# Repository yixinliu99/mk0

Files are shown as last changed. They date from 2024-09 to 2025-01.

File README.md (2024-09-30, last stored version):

# mk0
Modularized Keyboard 0

The goal of this project is to build a full-fledged and modularized keyboard from scratch, including PCBs and a case.

# Prelude
The last time I designed a PCB was for the final project of my Bachelor degree, which was almost 4 years ago. Some refreshing on how to design PCB is definetely needed for me. I have found https://wiki.ai03.com/books/pcb-design/chapter/pcb-designer-guide pretty useful as it covers not only general PCB designing but also how keyboards work.

# Roadmap
- PCB design (keyboard + STM32F303)
- Firmware. Probably will use some code from QMK (https://github.com/qmk/qmk_firmware)
- Case design
- Fabrication

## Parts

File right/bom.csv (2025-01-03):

Id | Designator | Footprint | Quantity | Designation | Supplier and ref
1 | C11,C3,C4,C12,C8,C10,C2 | C_0805_2012Metric_Pad1.18x1.45mm_HandSolder | 7 | 100nF
5 | SW2 | SW_SPST_CK_RS282G05A3 | 1 | SW_BOOT
7 | D20,D33,D3,D6,D27,D21,D28,D5,D23,D10,D18,D1,D25,D2,D19,D4,D30,D24,D11,D16,D31,D29,D13,D26,D7,D9,D12,D17,D32,D8,D22,D14,D15 | D_SOD-323_HandSoldering | 33 | D
11 | U1 | SOT-23 | 1 | LM3480-3.3
13 | R3 | R_0805_2012Metric_Pad1.20x1.40mm_HandSolder | 1 | 10K
15 | C1,C9,C7 | C_0805_2012Metric_Pad1.18x1.45mm_HandSolder | 3 | 4.7uF
16 | C14,C13 | C_0805_2012Metric_Pad1.18x1.45mm_HandSolder | 2 | 20pF
17 | J2 | Plug_3.5mm_CUI_SP-3541 | 1 | AudioJack4
18 | C5 | C_0805_2012Metric_Pad1.18x1.45mm_HandSolder | 1 | 1uF
21 | J1 | USB_C_Receptacle_HRO_TYPE-C-31-M-12 | 1 | USB_C_Receptacle_USB2.0_16P
22 | R2,R1 | R_0805_2012Metric_Pad1.20x1.40mm_HandSolder | 2 | 5.1K
33 | U2 | LQFP-48_7x7mm_P0.5mm | 1 | STM32F072CBTx
34 | SW1 | SW_SPST_CK_RS282G05A3 | 1 | SW_RESET
36 | Y1 | Crystal_SMD_2012-2Pin_2.0x1.2mm_HandSoldering | 1 | 8MHz
41 | C6 | C_0805_2012Metric_Pad1.18x1.45mm_HandSolder | 1 | 10nF
45 | R4 | R_0805_2012Metric_Pad1.20x1.40mm_HandSolder | 1 | 390
49 | J3 | Harwin_M20-89010xx_1x10_P2.54mm_Horizontal | 1 | Conn_ARM_JTAG_SWD_10

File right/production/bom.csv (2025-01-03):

Designator | Footprint | Quantity | Value | LCSC Part #
C1, C7, C9 | 0805 | 3 | 4.7uF
C10, C11, C12, C2, C3, C4, C8 | 0805 | 7 | 100nF
C13, C14 | 0805 | 2 | 20pF
C5 | 0805 | 1 | 1uF
C6 | 0805 | 1 | 10nF
D1, D10, D11, D12, D13, D14, D15, D16, D17, D18, D19, D2, D20, D21, D22, D23, D24, D25, D26, D27, D28, D29, D3, D30, D31, D32, D33, D4, D5, D6, D7, D8, D9 | D_SOD-323_HandSoldering | 33 | D
J1 | USB_C_Receptacle_HRO_TYPE-C-31-M-12 | 1 | USB_C_Receptacle_USB2.0_16P
J2 | Plug_3.5mm_CUI_SP-3541 | 1 | AudioJack4
J3 | Harwin_M20-89010xx_1x10_P2.54mm_Horizontal | 1 | Conn_ARM_JTAG_SWD_10
R1, R2 | 0805 | 2 | 5.1K
R3 | 0805 | 1 | 10K
R4 | 0805 | 1 | 390
SW1 | SW_SPST_CK_RS282G05A3 | 1 | SW_RESET
SW10 | SW_Cherry_MX_1.00u_Plate | 1 | tab
SW11 | SW_Cherry_MX_1.00u_Plate | 1 | q
SW12 | SW_Cherry_MX_1.00u_Plate | 1 | w
SW13 | SW_Cherry_MX_1.00u_Plate | 1 | e
SW14 | SW_Cherry_MX_1.00u_Plate | 1 | r
SW15 | SW_Cherry_MX_1.00u_Plate | 1 | t
SW16 | SW_Cherry_MX_1.00u_Plate | 1 | [
SW17 | SW_Cherry_MX_1.00u_Plate | 1 | caps
SW18 | SW_Cherry_MX_1.00u_Plate | 1 | a
SW19 | SW_Cherry_MX_1.00u_Plate | 1 | s
SW2 | SW_SPST_CK_RS282G05A3 | 1 | SW_BOOT
SW20 | SW_Cherry_MX_1.00u_Plate | 1 | d
SW21 | SW_Cherry_MX_1.00u_Plate | 1 | f
SW22 | SW_Cherry_MX_1.00u_Plate | 1 | g
SW23 | SW_Cherry_MX_1.00u_Plate | 1 | ->
SW24 | SW_Cherry_MX_2.00u_Plate | 1 | z
SW25 | SW_Cherry_MX_1.00u_Plate | 1 | z
SW26 | SW_Cherry_MX_1.00u_Plate | 1 | x
SW27 | SW_Cherry_MX_1.00u_Plate | 1 | c
SW28 | SW_Cherry_MX_1.00u_Plate | 1 | v
SW29 | SW_Cherry_MX_1.00u_Plate | 1 | b
SW3 | SW_Cherry_MX_1.00u_Plate | 1 | `
SW30 | SW_Cherry_MX_1.00u_Plate | 1 | custom2
SW31 | SW_Cherry_MX_1.00u_Plate | 1 | ctrl
SW32 | SW_Cherry_MX_1.00u_Plate | 1 | menu
SW33 | SW_Cherry_MX_1.00u_Plate | 1 | alt
SW34, SW35 | SW_Cherry_MX_1.00u_Plate | 2 | space
SW4 | SW_Cherry_MX_1.00u_Plate | 1 | 1
SW5 | SW_Cherry_MX_1.00u_Plate | 1 | 2
SW6 | SW_Cherry_MX_1.00u_Plate | 1 | 3
SW7 | SW_Cherry_MX_1.00u_Plate | 1 | 4
SW8 | SW_Cherry_MX_1.00u_Plate | 1 | 5
SW9 | SW_Cherry_MX_1.00u_Plate | 1 | -
U1 | SOT-23 | 1 | LM3480-3.3
U2 | LQFP-48_7x7mm_P0.5mm | 1 | STM32F072CBTx
Y1 | Crystal_SMD_2012-2Pin_2.0x1.2mm_HandSoldering | 1 | 8MHz

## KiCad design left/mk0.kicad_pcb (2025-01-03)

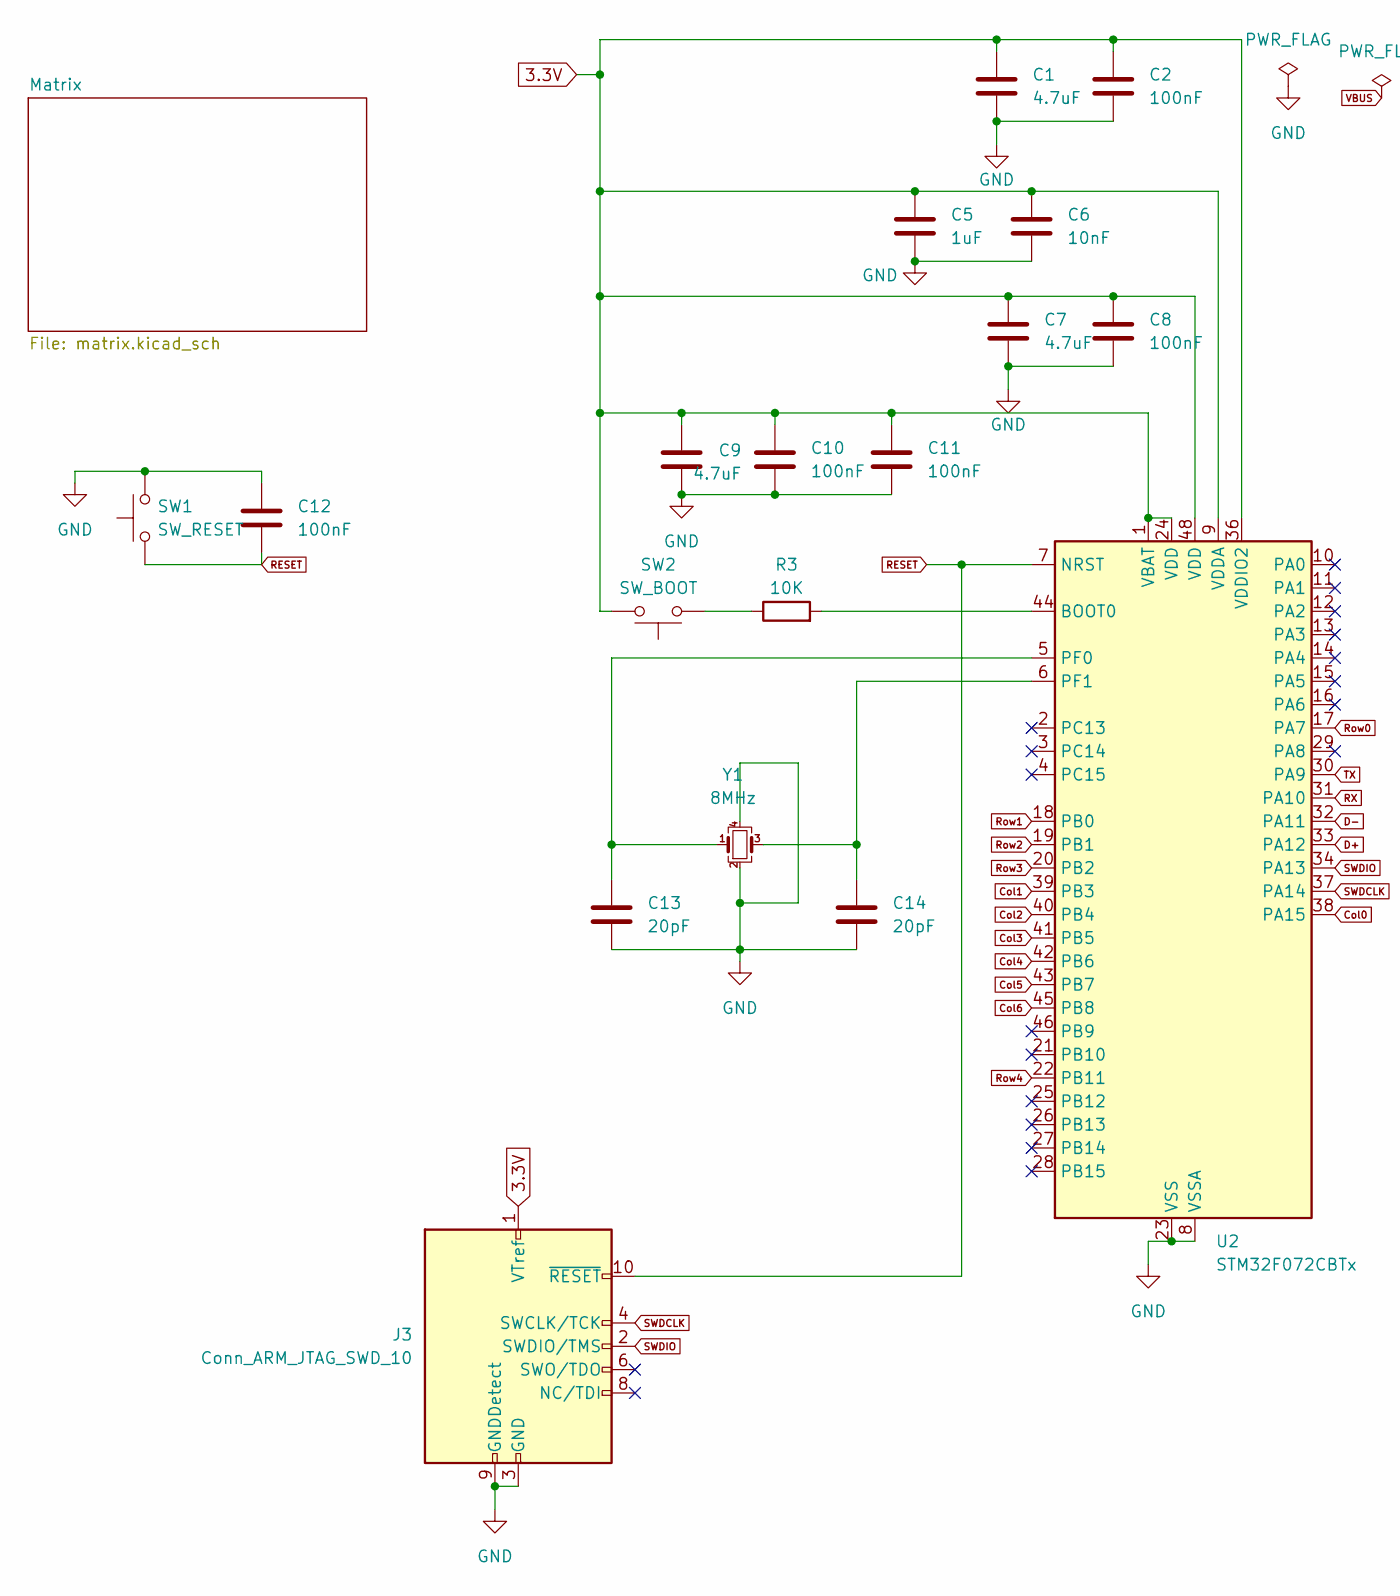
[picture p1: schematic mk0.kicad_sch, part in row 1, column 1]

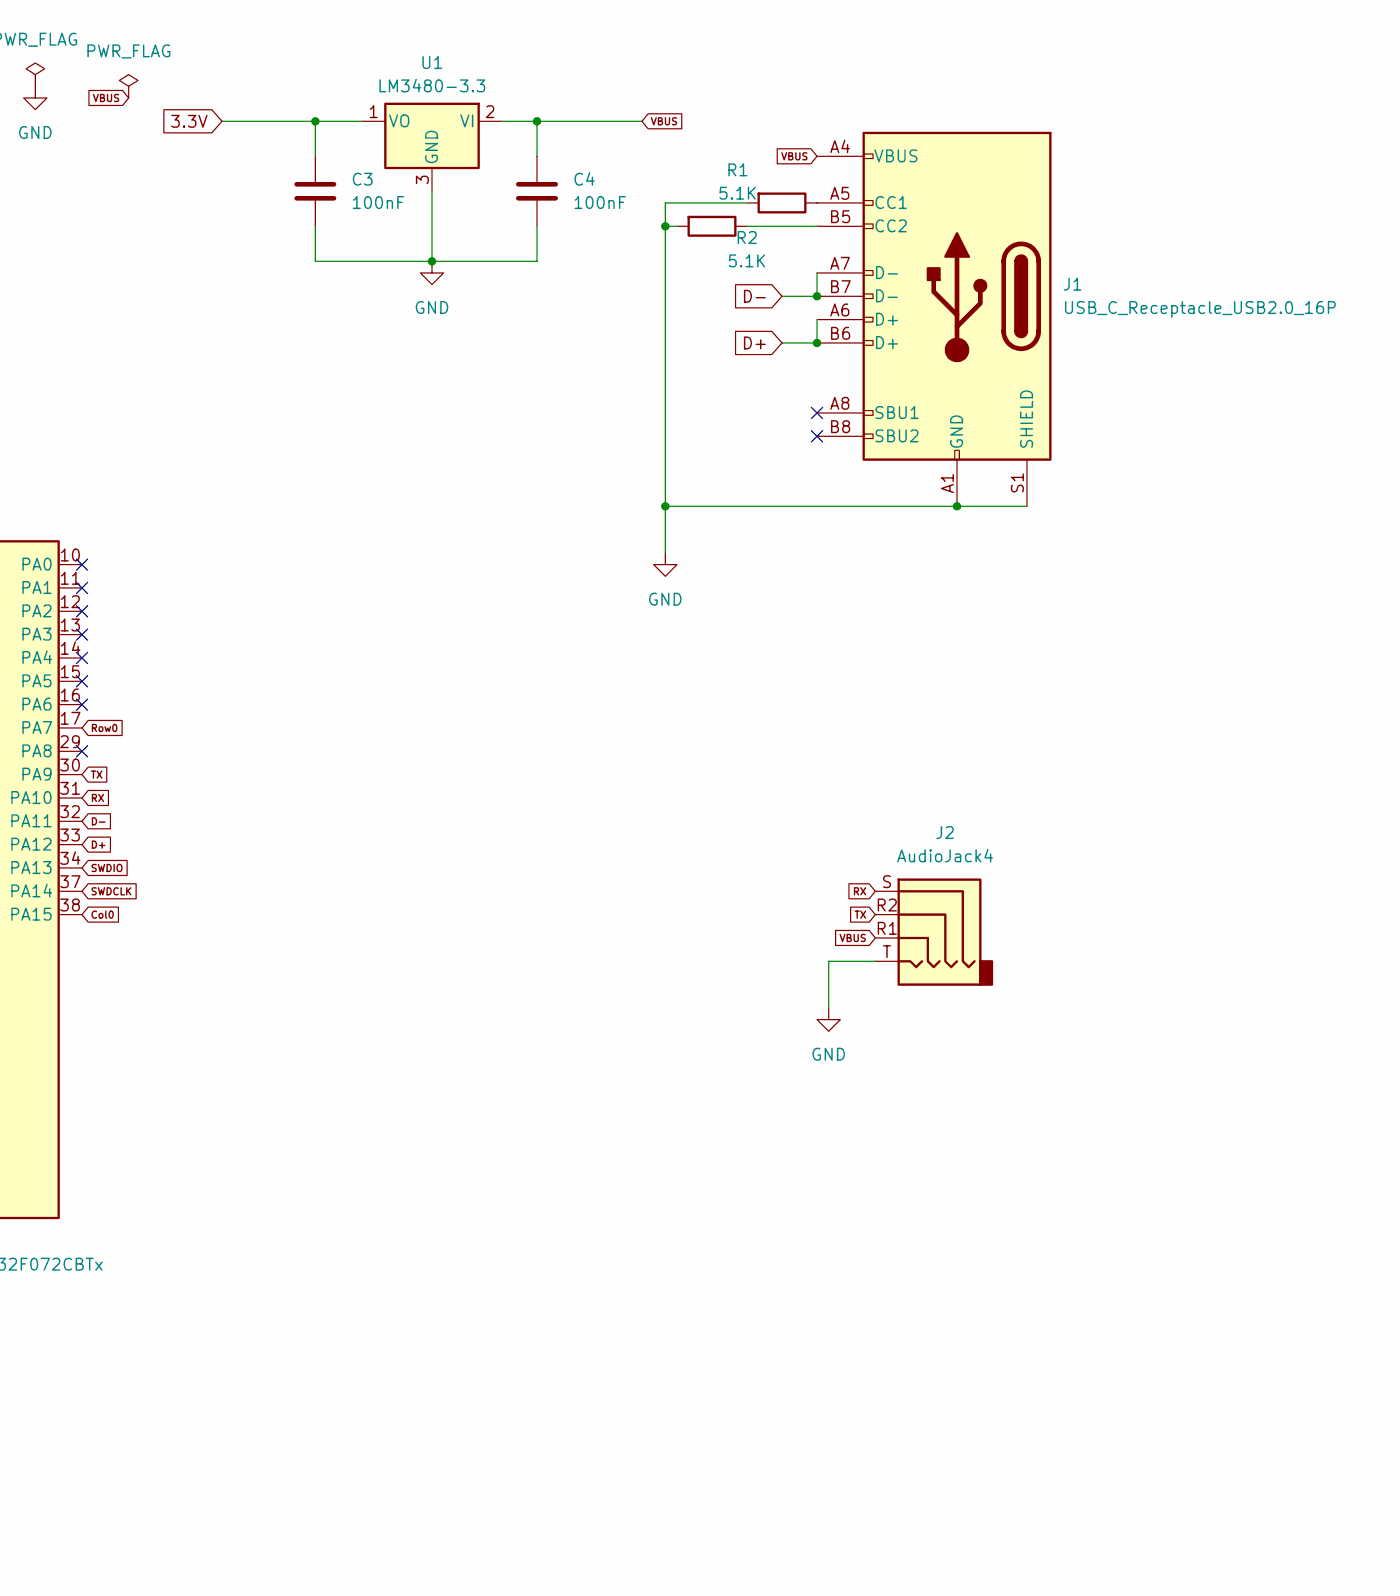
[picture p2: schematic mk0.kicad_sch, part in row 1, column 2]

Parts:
C1, C7, C9: 4.7uF; C_0805_2012Metric_Pad1.18x1.45mm_HandSolder
C2, C3, C4, C8, C10, C11, C12: 100nF; C_0805_2012Metric_Pad1.18x1.45mm_HandSolder
C5: 1uF; C_0805_2012Metric_Pad1.18x1.45mm_HandSolder
C6: 10nF; C_0805_2012Metric_Pad1.18x1.45mm_HandSolder
C13, C14: 20pF; C_0805_2012Metric_Pad1.18x1.45mm_HandSolder
J1: USB_C_Receptacle_USB2.0_16P; USB_C_Receptacle_HRO_TYPE-C-31-M-12
J2: AudioJack4; Plug_3.5mm_CUI_SP-3541
J3: Conn_ARM_JTAG_SWD_10; Harwin_M20-89010xx_1x10_P2.54mm_Horizontal
R1, R2: 5.1K; R_0805_2012Metric_Pad1.20x1.40mm_HandSolder
R3: 10K; R_0805_2012Metric_Pad1.20x1.40mm_HandSolder
SW1: SW_RESET; SW_SPST_CK_RS282G05A3
SW2: SW_BOOT; SW_SPST_CK_RS282G05A3
U1: LM3480-3.3; SOT-23
U2: STM32F072CBTx; LQFP-48_7x7mm_P0.5mm
Y1: 8MHz; Crystal_SMD_3225-4Pin_3.2x2.5mm_HandSoldering

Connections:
3.3V: C1.1, C2.1, C3.1, C5.1, C6.1, C7.1, C8.1, C9.1, C10.1, C11.1, J3.1 (VTref), SW2.2, U1.1 (VO), U2.1 (VBAT), U2.9 (VDDA), U2.24 (VDD), U2.36 (VDDIO2), U2.48 (VDD)
Col0: U2.38 (PA15); also elsewhere on the board
Col1: U2.39 (PB3); also elsewhere on the board
Col2: U2.40 (PB4); also elsewhere on the board
Col3: U2.41 (PB5); also elsewhere on the board
Col4: U2.42 (PB6); also elsewhere on the board
Col5: U2.43 (PB7); also elsewhere on the board
Col6: U2.45 (PB8); also elsewhere on the board
D+: J1.A6 (D+), J1.B6 (D+), U2.33 (PA12)
D-: J1.A7 (D-), J1.B7 (D-), U2.32 (PA11)
GND: C1.2, C2.2, C3.2, C4.2, C5.2, C6.2, C7.2, C8.2, C9.2, C10.2, C11.2, C12.1, C13.2, C14.2, J1.A1 (GND), J1.A12 (GND), J1.B1 (GND), J1.B12 (GND), J1.S1 (SHIELD), J2.T, J3.3 (GND), J3.5 (GND), J3.9 (GNDDetect), R1.2, R2.2, SW1.2, U1.3 (GND), U2.8 (VSSA), U2.23 (VSS), U2.35 (VSS), U2.47 (VSS), Y1.2, Y1.4
unnamed: J1.A5 (CC1), R1.1
unnamed: J1.B5 (CC2), R2.1
unnamed: R3.1, SW2.1
unnamed: R3.2, U2.44 (BOOT0)
unnamed: C13.1, U2.5 (PF0), Y1.1
unnamed: C14.1, U2.6 (PF1), Y1.3
RESET: C12.2, J3.10 (~RESET), SW1.1, U2.7 (NRST)
RX: J2.S, U2.31 (PA10)
Row0: U2.17 (PA7); also elsewhere on the board
Row1: U2.18 (PB0); also elsewhere on the board
Row2: U2.19 (PB1); also elsewhere on the board
Row3: U2.20 (PB2); also elsewhere on the board
Row4: U2.22 (PB11); also elsewhere on the board
SWDCLK: J3.4 (SWCLK/TCK), U2.37 (PA14)
SWDIO: J3.2 (SWDIO/TMS), U2.34 (PA13)
TX: J2.R2, U2.30 (PA9)
VBUS: C4.1, J1.A4 (VBUS), J1.A9 (VBUS), J1.B4 (VBUS), J1.B9 (VBUS), J2.R1, U1.2 (VI)

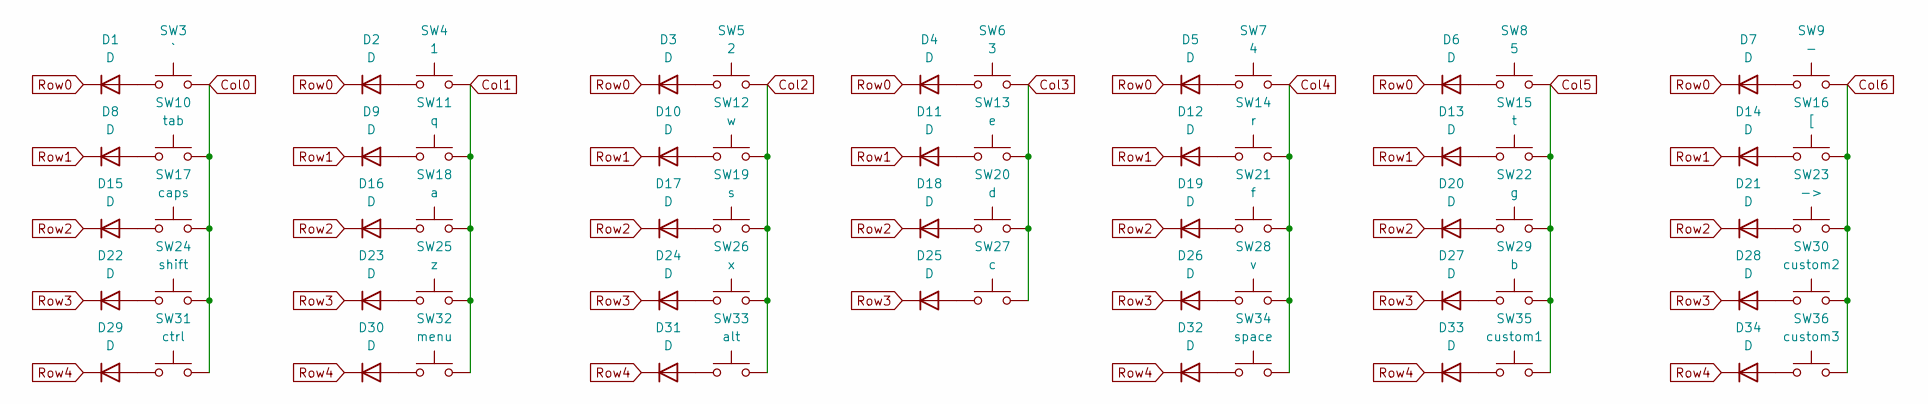
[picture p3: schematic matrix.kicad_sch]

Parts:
D1, D2, D3, D4, D5, D6, D7, D8, D9, D10, D11, D12, D13, D14, D15, D16, D17, D18, D19, D20, D21, D22, D23, D24, D25, D26, D27, D28, D29, D30, D31, D32, D33, D34: D; D_SOD-323_HandSoldering
SW3: `; SW_Cherry_MX_1.00u_Plate
SW4: 1; SW_Cherry_MX_1.00u_Plate
SW5: 2; SW_Cherry_MX_1.00u_Plate
SW6: 3; SW_Cherry_MX_1.00u_Plate
SW7: 4; SW_Cherry_MX_1.00u_Plate
SW8: 5; SW_Cherry_MX_1.00u_Plate
SW9: -; SW_Cherry_MX_1.00u_Plate
SW10: tab; SW_Cherry_MX_1.00u_Plate
SW11: q; SW_Cherry_MX_1.00u_Plate
SW12: w; SW_Cherry_MX_1.00u_Plate
SW13: e; SW_Cherry_MX_1.00u_Plate
SW14: r; SW_Cherry_MX_1.00u_Plate
SW15: t; SW_Cherry_MX_1.00u_Plate
SW16: [; SW_Cherry_MX_1.00u_Plate
SW17: caps; SW_Cherry_MX_1.00u_Plate
SW18: a; SW_Cherry_MX_1.00u_Plate
SW19: s; SW_Cherry_MX_1.00u_Plate
SW20: d; SW_Cherry_MX_1.00u_Plate
SW21: f; SW_Cherry_MX_1.00u_Plate
SW22: g; SW_Cherry_MX_1.00u_Plate
SW23: ->; SW_Cherry_MX_1.00u_Plate
SW24: shift; SW_Cherry_MX_1.00u_Plate
SW25: z; SW_Cherry_MX_1.00u_Plate
SW26: x; SW_Cherry_MX_1.00u_Plate
SW27: c; SW_Cherry_MX_1.00u_Plate
SW28: v; SW_Cherry_MX_1.00u_Plate
SW29: b; SW_Cherry_MX_1.00u_Plate
SW30: custom2; SW_Cherry_MX_1.00u_Plate
SW31: ctrl; SW_Cherry_MX_1.00u_Plate
SW32: menu; SW_Cherry_MX_1.00u_Plate
SW33: alt; SW_Cherry_MX_1.00u_Plate
SW34: space; SW_Cherry_MX_1.00u_Plate
SW35: custom1; SW_Cherry_MX_1.00u_Plate
SW36: custom3; SW_Cherry_MX_1.00u_Plate

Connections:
Col0: SW3.2, SW10.2, SW17.2, SW24.2, SW31.2; also elsewhere on the board
Col1: SW4.2, SW11.2, SW18.2, SW25.2, SW32.2; also elsewhere on the board
Col2: SW5.2, SW12.2, SW19.2, SW26.2, SW33.2; also elsewhere on the board
Col3: SW6.2, SW13.2, SW20.2, SW27.2; also elsewhere on the board
Col4: SW7.2, SW14.2, SW21.2, SW28.2, SW34.2; also elsewhere on the board
Col5: SW8.2, SW15.2, SW22.2, SW29.2, SW35.2; also elsewhere on the board
Col6: SW9.2, SW16.2, SW23.2, SW30.2, SW36.2; also elsewhere on the board
unnamed: D1.2 (A), SW3.1
unnamed: D2.2 (A), SW4.1
unnamed: D3.2 (A), SW5.1
unnamed: D4.2 (A), SW6.1
unnamed: D5.2 (A), SW7.1
unnamed: D6.2 (A), SW8.1
unnamed: D7.2 (A), SW9.1
unnamed: D8.2 (A), SW10.1
unnamed: D9.2 (A), SW11.1
unnamed: D10.2 (A), SW12.1
unnamed: D11.2 (A), SW13.1
unnamed: D12.2 (A), SW14.1
unnamed: D13.2 (A), SW15.1
unnamed: D14.2 (A), SW16.1
unnamed: D15.2 (A), SW17.1
unnamed: D16.2 (A), SW18.1
unnamed: D17.2 (A), SW19.1
unnamed: D18.2 (A), SW20.1
unnamed: D19.2 (A), SW21.1
unnamed: D20.2 (A), SW22.1
unnamed: D21.2 (A), SW23.1
unnamed: D22.2 (A), SW24.1
unnamed: D23.2 (A), SW25.1
unnamed: D24.2 (A), SW26.1
unnamed: D25.2 (A), SW27.1
unnamed: D26.2 (A), SW28.1
unnamed: D27.2 (A), SW29.1
unnamed: D28.2 (A), SW30.1
unnamed: D29.2 (A), SW31.1
unnamed: D30.2 (A), SW32.1
unnamed: D31.2 (A), SW33.1
unnamed: D32.2 (A), SW34.1
unnamed: D33.2 (A), SW35.1
unnamed: D34.2 (A), SW36.1
Row0: D1.1 (K), D2.1 (K), D3.1 (K), D4.1 (K), D5.1 (K), D6.1 (K), D7.1 (K); also elsewhere on the board
Row1: D8.1 (K), D9.1 (K), D10.1 (K), D11.1 (K), D12.1 (K), D13.1 (K), D14.1 (K); also elsewhere on the board
Row2: D15.1 (K), D16.1 (K), D17.1 (K), D18.1 (K), D19.1 (K), D20.1 (K), D21.1 (K); also elsewhere on the board
Row3: D22.1 (K), D23.1 (K), D24.1 (K), D25.1 (K), D26.1 (K), D27.1 (K), D28.1 (K); also elsewhere on the board
Row4: D29.1 (K), D30.1 (K), D31.1 (K), D32.1 (K), D33.1 (K), D34.1 (K); also elsewhere on the board

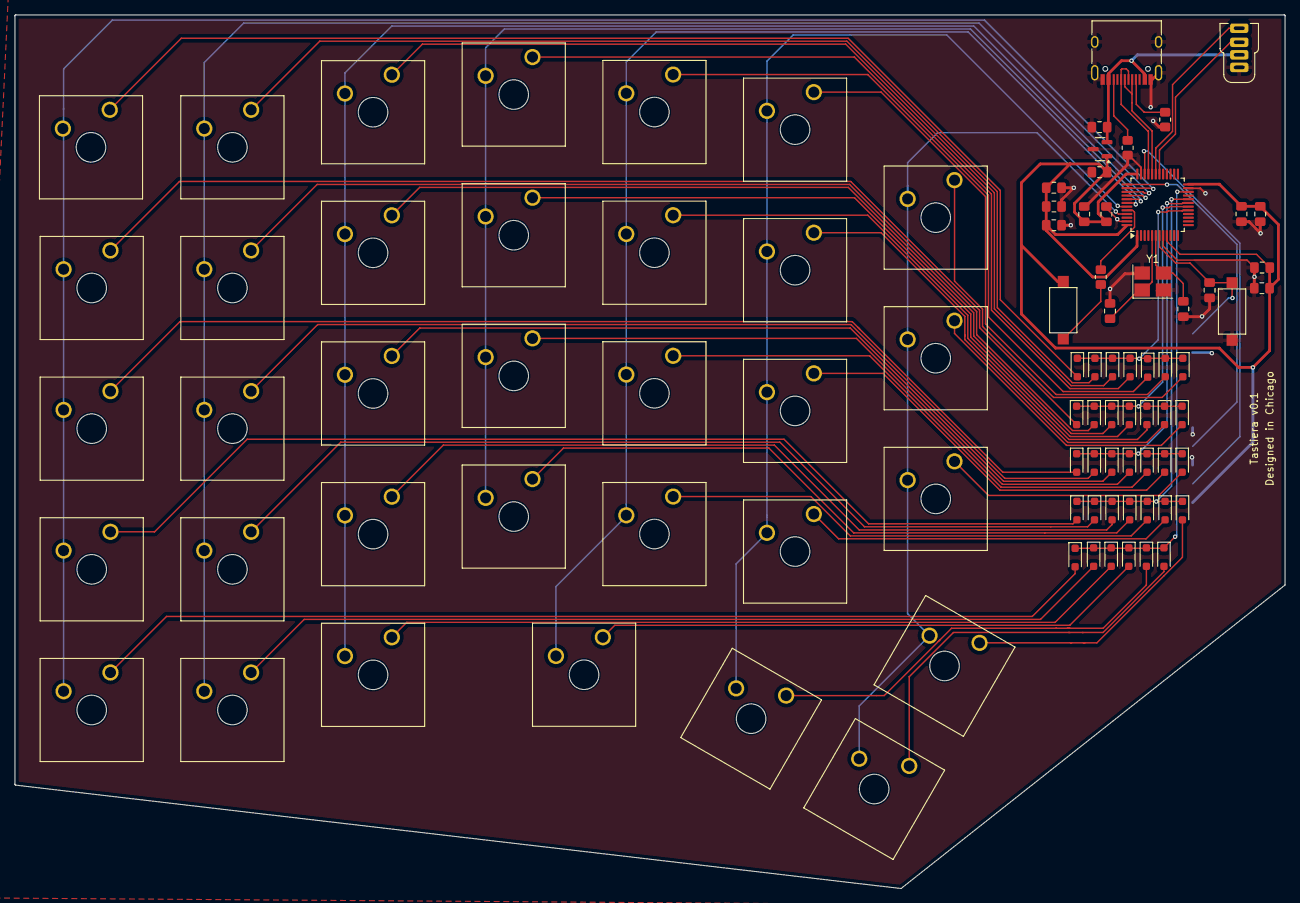
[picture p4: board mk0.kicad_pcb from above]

Board: 2 copper layers, 172.0 x 118.3 mm, 93 parts (1 on the bottom side), 62 nets.

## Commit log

2024-12-18 Completed left PCB, switches routing pending
    [mk0.kicad_pcb, mk0.kicad_sch]
2024-12-19 Finish routing for switches
    [mk0.kicad_pcb, mk0.kicad_sch]
2024-12-24 Complete left halve
    [mk0-B_Cu.gbl, mk0-B_Mask.gbs, mk0-B_Paste.gbp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]
2025-01-01 fix left halve & start right halve
    [matrix.kicad_sch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]
2025-01-02 Finish right halve
    [matrix.kicad_sch, mk0.kicad_pcb, right.kicad_pcb]
2025-01-02 left halve plate holes & python script
    [mk0.kicad_pcb, right.kicad_pcb]
2025-01-03 change cristals
    [bom.csv, designators.csv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]
